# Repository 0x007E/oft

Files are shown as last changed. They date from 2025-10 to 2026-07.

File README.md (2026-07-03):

  

# `OFT` - Optical Fibre Transceiver

The `OFT` project is based on a fibre optic transmitter an receiver ([FB104](#additional-information)). The transmitter is based on a high-output medium-speed infrared LED while the transceiver is built on a high-sensitivity NPN phototransistor. Both are housed in a connector-less style plastic fiber optic package. The transmitter has a typical peak wavelength of `930nm`. The bandwith of the receiver is between `400nm` to `1100nm`. The maximum photosensitivity is around `870nm`. The receiver and transmitter is connected with an `RX` and `TX` LED over a `NE555` timer circuit to indicate if a data transmission occurrs.

> Note that the `IF-D92` is suitable for digital data links at rates up to `20kbps`!

| Experience | Level |
|:---|:-----:|
| Soldering | ?% |
| Mechanical  | ?% |

# Downloads

| Type | File | Description |
|:---:|:---:|:---|
| Schematic | [pdf](https://github.com/0x007E/oft/releases/latest/download/schematic.pdf) / [cadlab](https://cadlab.io/project/29648/main/files) | Schematic files |
| Board | [pdf](https://github.com/0x007E/oft/releases/latest/download/pcb.pdf) / [cadlab](https://cadlab.io/project/29648/main/files) | Board file |
| Drill | [pdf](https://github.com/0x007E/oft/releases/latest/download/drill.pdf) | Drill file |
| BoM | [xlsx](https://github.com/0x007E/oft/releases/latest/download/bom.xlsx) / [html](https://github.com/0x007E/oft/releases/latest/download/ibom.html) | Bill of Material as Excel/interactive HTML |
| PCB | [zip](https://github.com/0x007E/oft/releases/latest/download/kicad.zip) / [tar](https://github.com/0x007E/oft/releases/latest/download/kicad.tar.gz) | KiCAD/Gerber/BoM/Drill files |
| Mechanical | [zip](https://github.com/0x007E/oft/releases/latest/download/freecad.zip) / [tar](https://github.com/0x007E/oft/releases/latest/download/freecad.tar.gz) | FreeCAD/Housing and PCB (STEP/STL) files |

# Hardware

There are two parts of the hardware. The pcb and the housing of the `OFT`. The pcb is created with [KiCAD](#additional-information) and the housing with `FreeCAD`. All files are built with `github actions` so that they are ready for a production environment. The housing is printed with a 3D-printer (`Dremel 3D40`).

## PCB

The circuit board is populated on both sides (Top, Bottom). The best way for soldering the `SMD` components is within a vapor phase soldering system and for the `THT` components with a standard soldering system.

### Top Layer

Top Layer

### Bottom Layer

Bottom Layer

## Mechanical

The housing has a tolerance of `0.2mm` on each side of the case. So the pcb should fit perfectly in the housing. The tolerance can be modified with `FreeCAD` in the `Parameter` Spreadsheet.

### Assembled

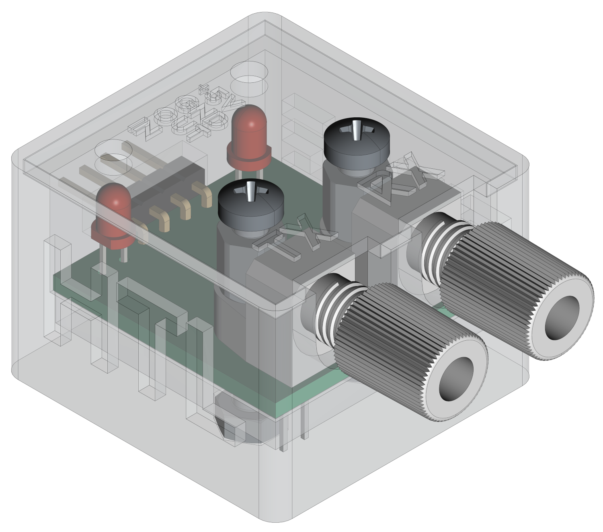
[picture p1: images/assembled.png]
Assembled


#### Exploded

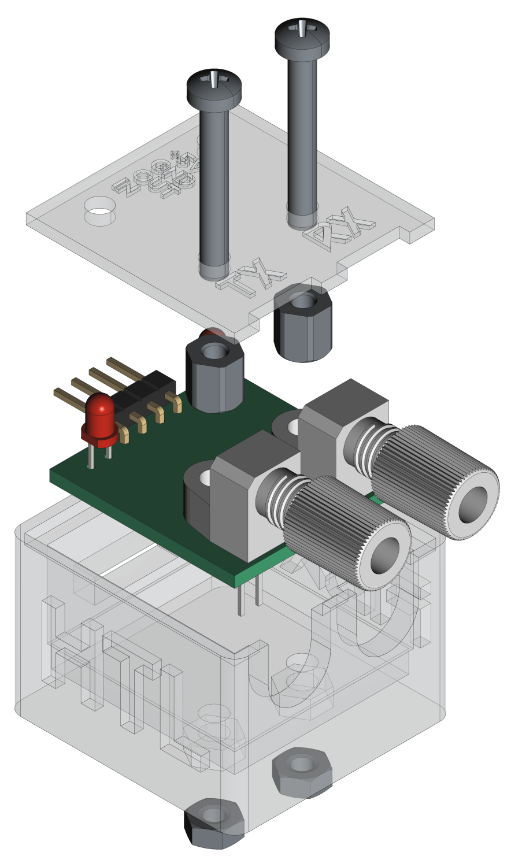
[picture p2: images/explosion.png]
Exploded


# Connection/Setup

The `OFT` is powerd with `5V`. The `RX` pin serves as an output and stores the received data at the output so that it can be read by the device. The `TX` pin servs as an input and sends the received data at the input over the fibre channel. The levels of both pins are `LOW = 0V` and `HIGH = 5V`.

``` bash
#
#                                      +----------------+      +---------------------+
#                                      |    U       +---+---+  |                     |
#                                      |    S       |  USB  |--+ +-----------------+ |
#                                      |    B       +---+---+  | | TeraTerm        | |
#              +-------------+         |    /           |      | | ~~~~~~~~        | |
#              |      O      |         |    U           |      | | ~~~~~           | |
#            +--+--+  F   +--+--+   +--+--+ A           |      | | ~~~~~~~~~~~~    | |
#      L +---+ ORX |  T   | VCC +---+ VCC | R           |      | |                 | |
#      O |   +--+--+      | GND +---+ GND | T  +-+      |      | +-----------------+ |
#      O |      |         +-----+   +-----+   / /       |      |                     |
#      P |   +--+--+      | RXD +---+ RXD | +-+-+-+-----+      | Computer            |
#      B +---+ OTX |      | TXD +---+ TXD | | 5V  | 3V3 |      |                     |
#      A     +--+--+      +--+--+   +--+--+ +-----+-----+      +---------------------+
#      C       |             |
#      K       +-------------+                                            
#
```

> The maximum baudrate should be about `~19200bps`!

# Additional Information

| Type | Link | Description |
|:---:|:---:|:---|
| IF-E10 | [pdf](https://i-fiberoptics.com/pdf/if-e10.pdf) | Optical fibre receiver and transmitter |
| NE555 | [pdf](https://www.ti.com/lit/ds/symlink/se555.pdf) | Universal timer and oscillator |
| KiCAD | [web](https://www.kicad.org/) | KiCAD project page |
| FreeCAD | [web](https://www.freecad.org/) | FreeCAD project page |

---

R. GAECHTER

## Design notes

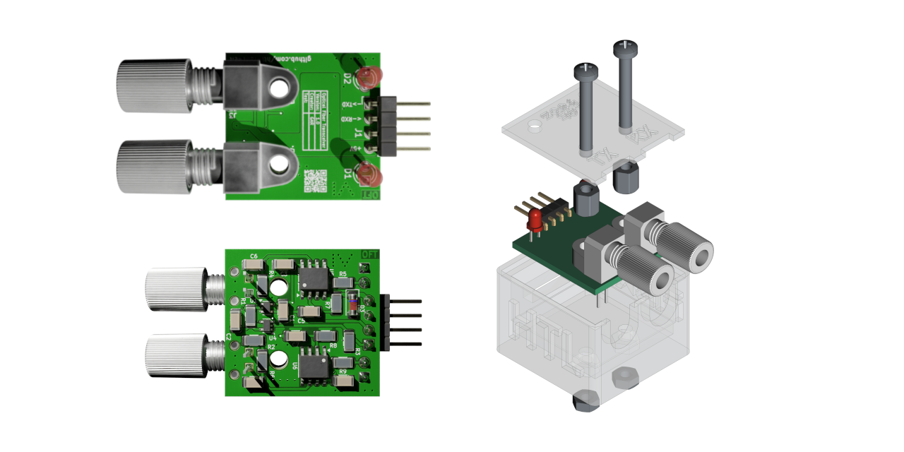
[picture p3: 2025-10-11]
images/social.png

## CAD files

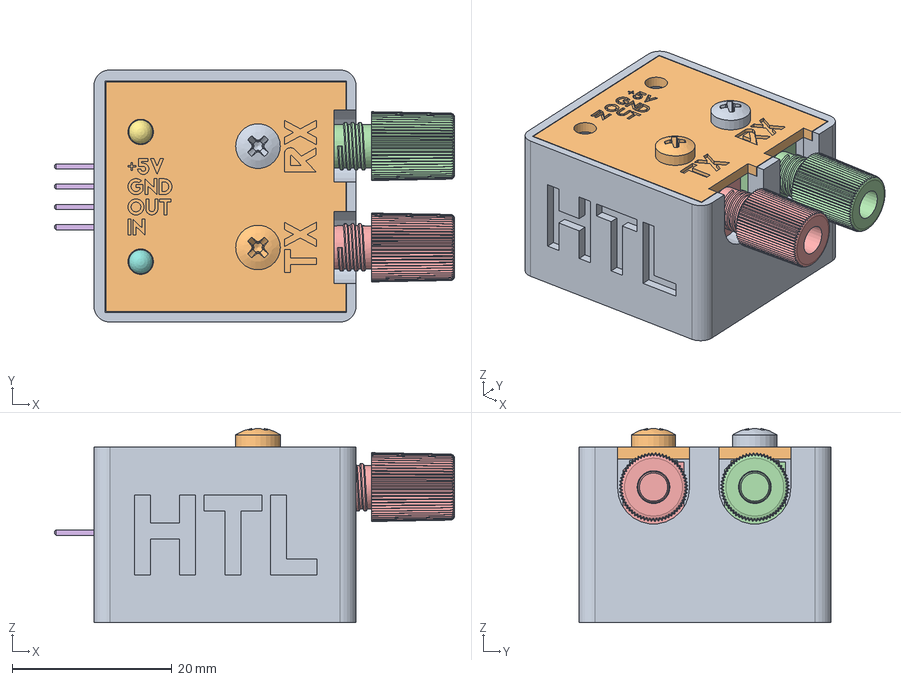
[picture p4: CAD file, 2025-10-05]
mechanical/housing.FCStd
50.1 x 31.6 x 24.3 mm
Case
Acrylglass
Pcb_8c87
J2_Emitter_65586149a813
J3_Emitter_f4ef52d364f1
J1_PinHeader_1x04_P254mm_Horizontal_09bfcaf4bf53
D1_LED_D3.0mm_fa1b82c3b3fe
D2_LED_D3.0mm_0670091fe9f8
R5_R_1206_3216Metric_c86079678e7a
D3_D_MiniMELF_Standard_404524d1c563
C7_C_1206_3216Metric_2a96b21a8bc3
U4_SOT_353_SC_70_5_4126141b7bcb
U1_SOT_353_SC_70_5_ced3e6da737e
U5_SOIC_8_39x49mm_P127mm_71cf3c092788
R4_R_1206_3216Metric_40be4dbe614b
R6_R_1206_3216Metric_c0b4eb30ff3f
C8_C_1206_3216Metric_7ffbbb58a28f
R8_R_1206_3216Metric_c8458dc816cc
R9_R_1206_3216Metric_223e748fa189
C6_C_1206_3216Metric_744c5df59782
R3_R_1206_3216Metric_30f5223ead03
R2_R_1206_3216Metric_fc434a9371ed
C1_C_1206_3216Metric_c4200b641963
C4_C_1206_3216Metric_b52908205fcc
R7_R_1206_3216Metric_0de481803c9c
U6_SOIC_8_39x49mm_P127mm_4fbd13a4defe
C2_C_1206_3216Metric_bf5b6597c792
R1_R_1206_3216Metric_ef2ff6179822
C5_C_1206_3216Metric_2f9b2613b12d
C3_C_1206_3216Metric_c65fbffed25c
M3x6x5.5-Spacer
M3x6x5.5-Spacer001
M3x22-Screw
M3x22-Screw001
M3-Nut
M3-Nut001

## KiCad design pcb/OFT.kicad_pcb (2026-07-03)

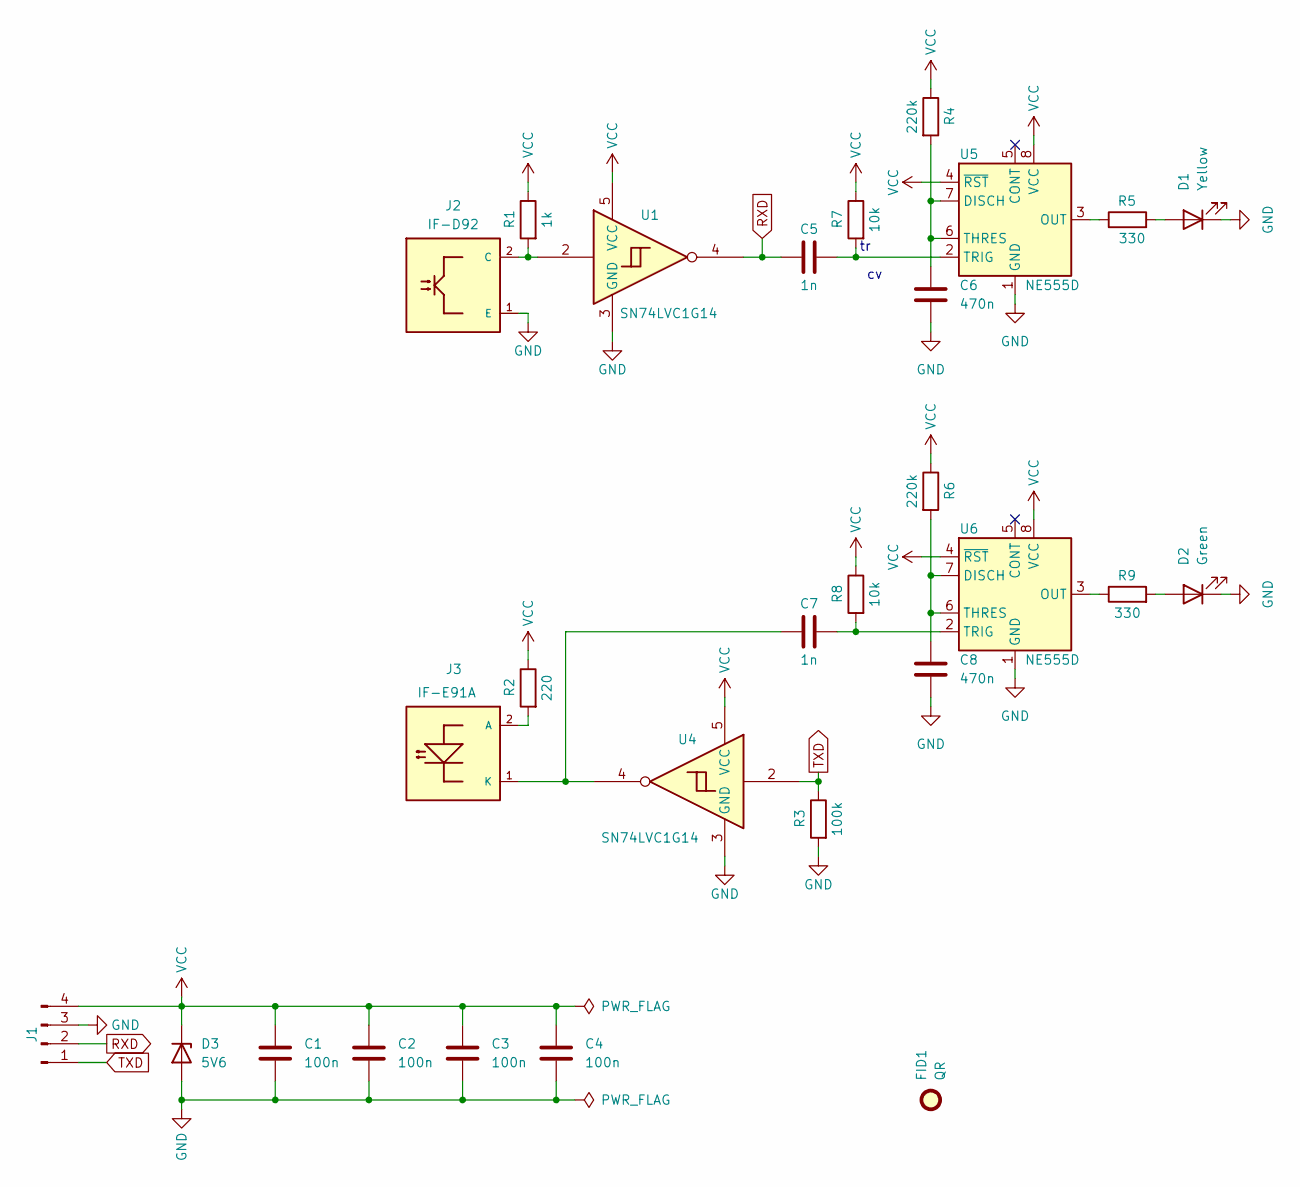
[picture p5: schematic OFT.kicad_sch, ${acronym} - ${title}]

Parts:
C1, C2, C3, C4: 100n; C_1206_3216Metric
C5, C7: 1n; C_1206_3216Metric
C6, C8: 470n; C_1206_3216Metric
D1: Yellow; LED_D3.0mm
D2: Green; LED_D3.0mm
D3: 5V6; D_MiniMELF
FID1: QR; QR_0x007e_very_small
J1: Conn_01x04_Pin; PinHeader_1x04_P2.54mm_Horizontal
J2: IF-D92
J3: IF-E91A
R1: 1k; R_1206_3216Metric
R2: 220; R_1206_3216Metric
R3: 100k; R_1206_3216Metric
R4, R6: 220k; R_1206_3216Metric
R5, R9: 330; R_1206_3216Metric
R7, R8: 10k; R_1206_3216Metric
U1, U4: SN74LVC1G14; SOT-353_SC-70-5
U5, U6: NE555D; SOIC-8_3.9x4.9mm_P1.27mm

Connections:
GND: C1.2, C2.2, C3.2, C4.2, C6.2, C8.2, D1.1 (K), D2.1 (K), D3.2 (A), J1.3, J2.1 (E), R3.2, U1.3 (GND), U4.3 (GND), U5.1 (GND), U6.1 (GND)
unnamed: D1.2 (A), R5.2
unnamed: D2.2 (A), R9.2
unnamed: J2.2 (C), R1.2, U1.2
unnamed: J3.2 (A), R2.2
unnamed: C7.1, J3.1 (K), U4.4
unnamed: C6.1, R4.2, U5.6 (THRES), U5.7 (DISCH)
unnamed: R5.1, U5.3 (OUT)
unnamed: C5.2, R7.2, U5.2 (TRIG)
unnamed: C8.1, R6.2, U6.6 (THRES), U6.7 (DISCH)
unnamed: R9.1, U6.3 (OUT)
unnamed: C7.2, R8.2, U6.2 (TRIG)
RXD: C5.1, J1.2, U1.4
TXD: J1.1, R3.1, U4.2
VCC: C1.1, C2.1, C3.1, C4.1, D3.1 (K), J1.4, R1.1, R2.1, R4.1, R6.1, R7.1, R8.1, U1.5 (VCC), U4.5 (VCC), U5.4 (~RST), U5.8 (VCC), U6.4 (~RST), U6.8 (VCC)

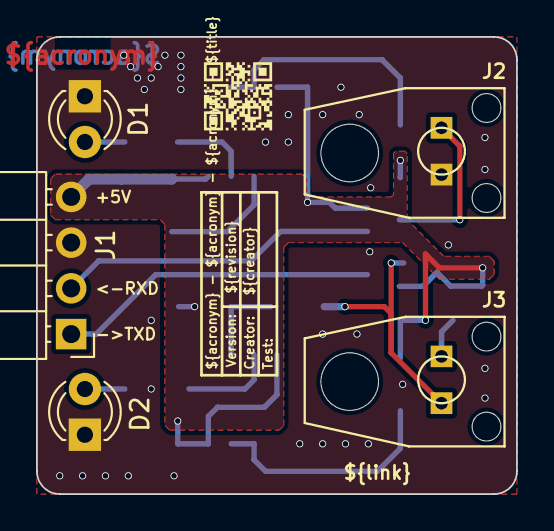
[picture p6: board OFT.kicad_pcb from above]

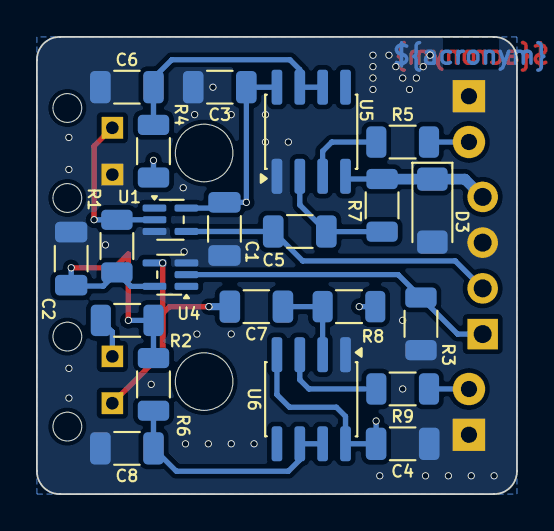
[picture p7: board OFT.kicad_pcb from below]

Board: 2 copper layers, 26.7 x 25.4 mm, 28 parts (22 on the bottom side), 15 nets.

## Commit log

2025-10-05 Adapt filter for drc warning
2025-10-05 Remove TechDraw
    [housing.FCStd]
2025-10-06 Change partlist vendors
    [OFT.kicad_pcb, OFT.kicad_sch]
2026-02-02 Fix wrong vendor id
    [OFT.kicad_pcb, OFT.kicad_sch]
2026-02-02 Add value to BoM
2026-07-03 Update to KiCAD 9
    [OFT.kicad_pcb, OFT.kicad_sch]
2026-07-03 Rename/Add/Remove bom fields
    [OFT.kicad_pcb, OFT.kicad_sch]
2026-07-03 Optimize receiver load resistor
    [OFT.kicad_pcb, OFT.kicad_sch]
2026-07-03 Rounding up board corners
    [OFT.kicad_pcb]
2026-07-03 Remove description from J1
    [OFT.kicad_sch]
2026-07-03 Rename fiducial reference
    [OFT.kicad_pcb, OFT.kicad_sch]

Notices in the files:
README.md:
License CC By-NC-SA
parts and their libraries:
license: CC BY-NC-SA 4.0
